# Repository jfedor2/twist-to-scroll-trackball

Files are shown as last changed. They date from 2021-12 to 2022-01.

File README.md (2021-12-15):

# DIY trackball with twist-to-scroll

This repository contains design files and code that can be used to make a fully programmable four-button USB trackball that can scroll by rotating the ball around the vertical axis. It achieves that by having two optical sensors.

Here's a [video](https://www.youtube.com/watch?v=dVZCyMe__IE) demonstrating the twist-to-scroll function.

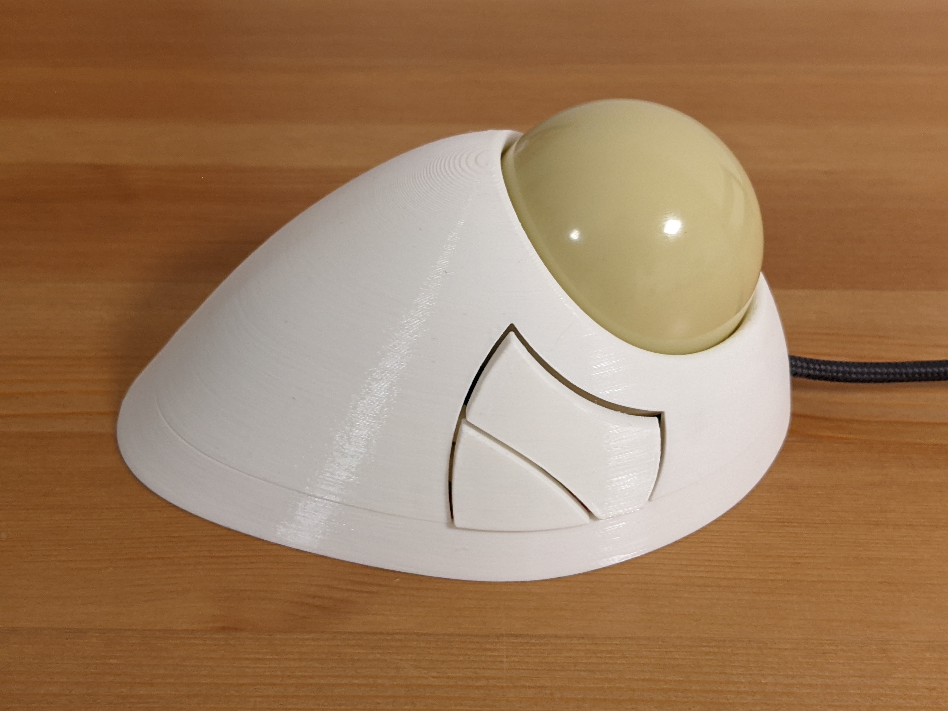
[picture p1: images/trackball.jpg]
Trackball photo


It uses the following components:

* 57.2mm billiard ball
* two PMW3360 optical sensors
* [RP2040+PMW3360 PCB](https://github.com/jfedor2/rp2040-pmw3360)
* [PMW3360 breakout PCB](https://github.com/jfedor2/pmw3360-breakout) for the second sensor
* [button switch mount PCBs](https://github.com/jfedor2/mouse-switch-mount-pcb)
* [3D printed case](3d-models)
* Omron D2FC switches (or similar)
* 2.5mm zirconium oxide (or silicon nitride) bearing balls
* M3x4 screws for mounting the main PCB and assembling the case
* M2x4 screws for mounting the buttons and the secondary PCBs
* USB cable (cut off the device end and solder the wires directly to the PCB)

The main PCB uses the RP2040 chip from Raspberry Pi. The firmware supports remapping of ball and button functions using a configuration tool without the need to recompile the source code. All the configuration is stored on device, so the configuration tool is only needed to change the settings, not during normal use.

The twist-to-scroll function is a work in progress, but it already works pretty well. High resolution scroll is supported (on Windows and in some cases on Linux).

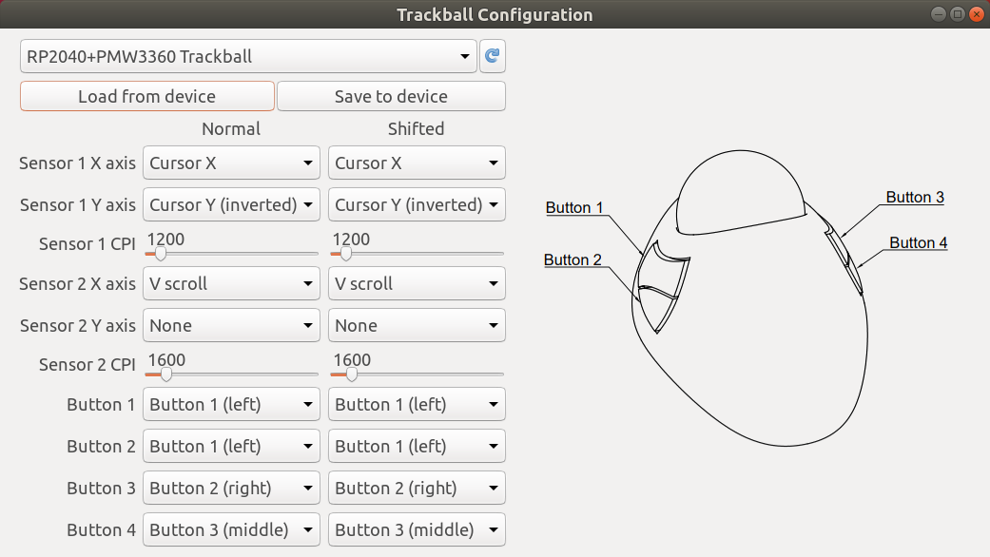
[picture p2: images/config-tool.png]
Configuration tool UI screenshot


So far I only tested the configuration tool on Linux, but it should in theory run on Windows and Mac as well. I will try to provide ready-to-use packages in the future.

The provided [UF2 file](firmware/trackball.uf2) can be used to flash the firmware onto the device. When first connected, a "RPI-RP2" drive will show up and you flash the chip by copying the UF2 file to that drive. If you want to flash it again, hold the BOOT button and press the RESET button on the board.

I printed the case parts with 0.2mm layer height. The top and bottom parts don't need supports, the buttons do.

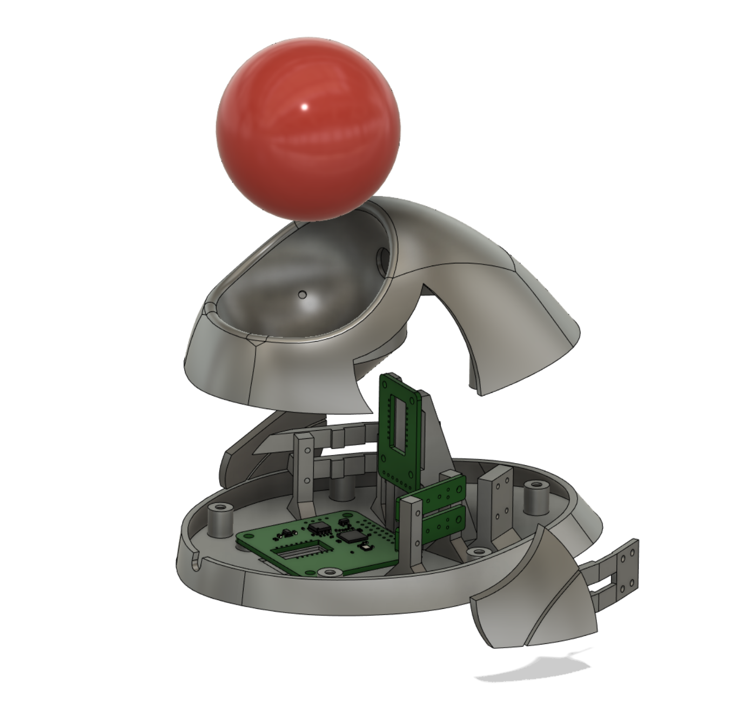
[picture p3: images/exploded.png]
Exploded view


The pin numbers are defined at the top of [trackball.cc](firmware/src/trackball.cc).

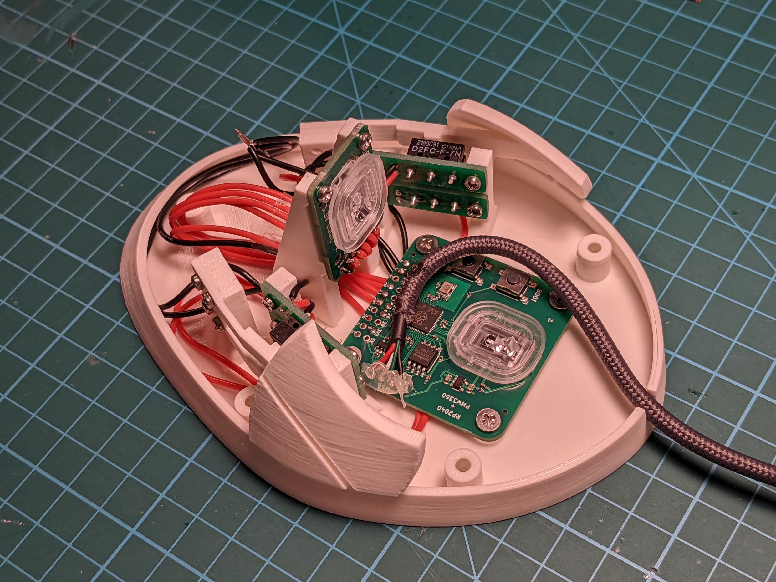
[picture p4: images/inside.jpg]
Insides of the case


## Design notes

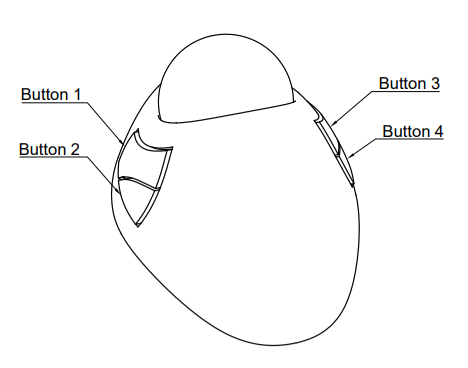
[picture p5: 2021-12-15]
config-tool/trackball.png

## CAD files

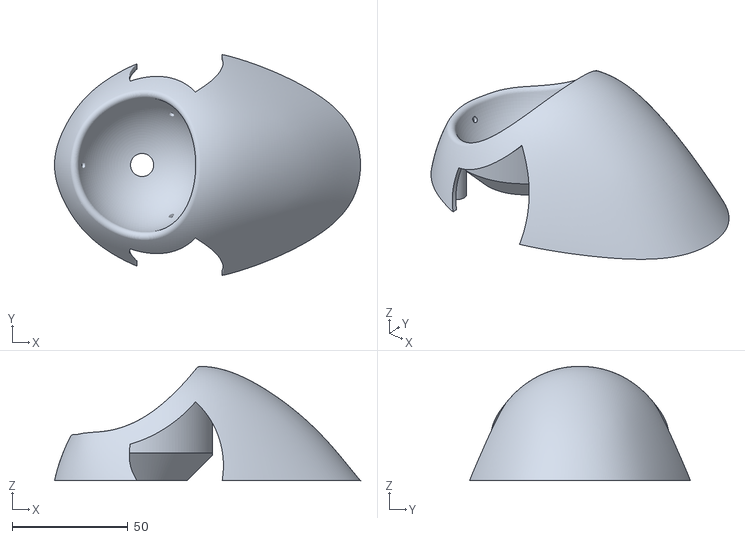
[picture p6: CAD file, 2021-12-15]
3d-models/Trackball13-Top.stl
132.3 x 95.6 x 49.5

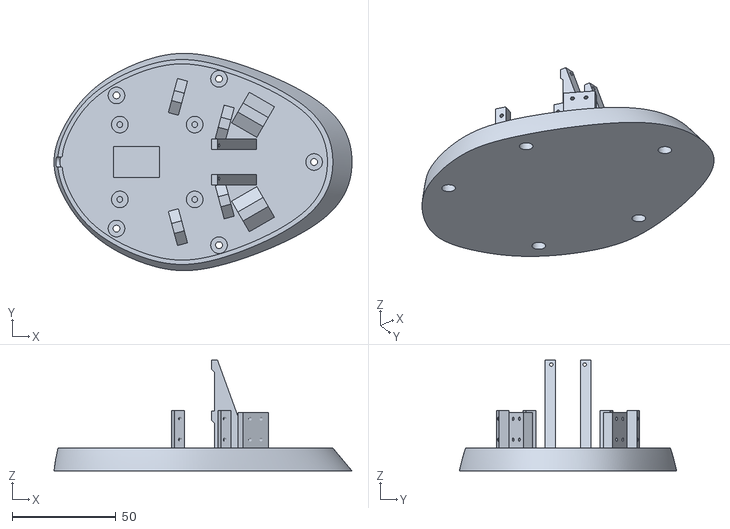
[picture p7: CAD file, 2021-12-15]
3d-models/Trackball13-Bottom.stl
143.3 x 104.5 x 53.2

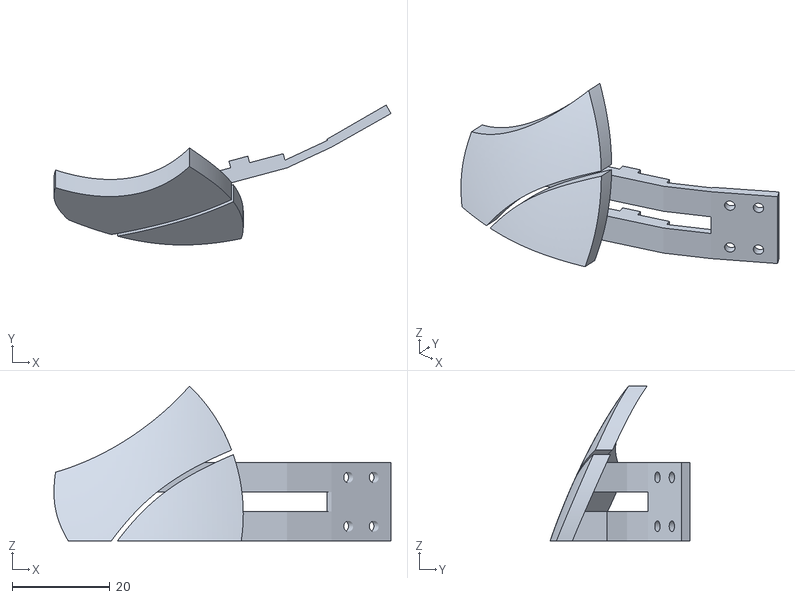
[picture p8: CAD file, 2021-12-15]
3d-models/Trackball13-Buttons-Left.stl
68.9 x 28.6 x 31.7

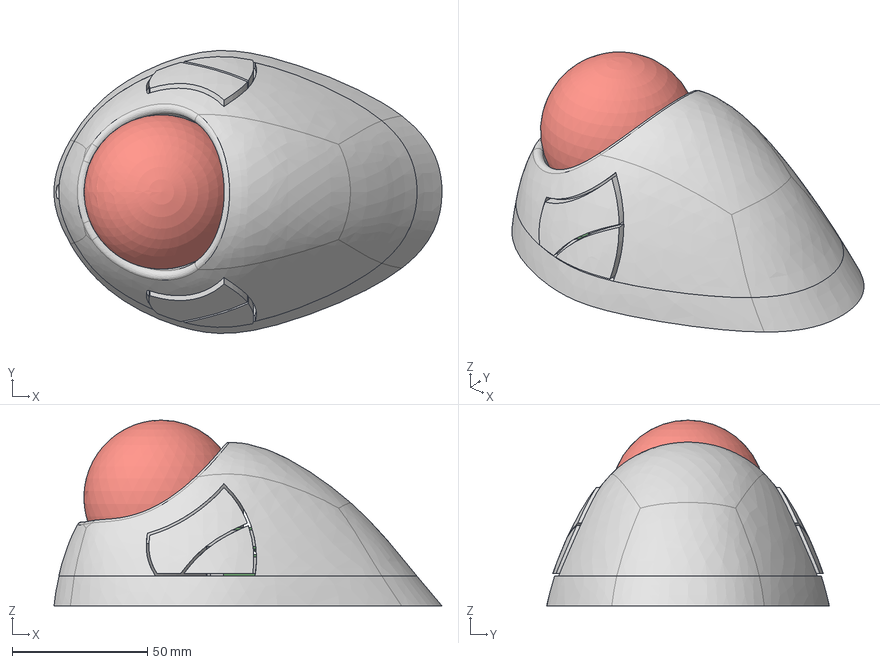
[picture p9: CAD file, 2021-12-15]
3d-models/Trackball13.step
143.3 x 104.4 x 68.6 mm

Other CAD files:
3d-models/Trackball13.f3z

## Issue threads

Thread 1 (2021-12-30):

3D source files

JonnyHaystack, 2021-12-30:
Hi, would you mind uploading the source files for the 3D models? At the moment I'm just trying to put a USB C port cutout in the wall instead of the hole for the cable, but it's a bit tricky to manually patch the cable hole closed. Alternatively, if you could just upload an STL for the bottom part without the cable hole that would make it a lot easier to edit it with a custom port cutout.

I was mostly able to do it with some hacky editing but it comes out a bit weird in the slicer and I'm not sure if it might cause problems when printing :-/
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

jfedor2, 2021-12-31:
I can upload the source file, but for stuff like this you should really start with the STEP file, not the STLs. It won't give you my editing timeline, but removing the cable cutout is as easy as selecting three faces and pressing the del key (at least in Fusion 360).

JonnyHaystack, 2021-12-31:
Thanks. I use OpenSCAD usually so I can't really do anything with the STEP file in that I don't think.

jfedor2, 2021-12-31:
Yeah, the "source" I'm talking about would be a Fusion 360 file, so not useful in OpenSCAD either I'm afraid.

JonnyHaystack, 2021-12-31:
Yeah I know, but in this case I would just remove the cable cutout in Fusion 360 and export it as an STL, then do my thing in OpenSCAD.

Oh, and on an unrelated note, I accidentally printed one of the mouse button things without supports, and it actually printed fine and came out better than the ones that I printed with supports. The first layer had a couple of droopy bits which I clipped off, but other than that it turns out great. My printer isn't anything crazy good either.
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

jfedor2, 2022-01-01:
I added the Fusion 360 file. Good luck!

Closed 2022-01-01.

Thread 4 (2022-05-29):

Why a work in progress?

Steve-Wax, 2022-05-29:
I like your design.  It looks like a cross between the Logitech Trackman Marble Mouse and the Kensington Slim Blade with the best features of each.  I'm thinking of building one.  You mention that the scrolling is a work in progress.  I'm curious why you think that is and what needs to be improved.  Do you think it is good for regular use or should I plan to do some work on it first.  Thanks for the design.

jfedor2, 2022-05-29:
Thank you for the kind words.

I think the scroll works pretty well as it is, but it should ideally be other users to confirm that as I may be a bit biased. I wrote it's a work in progress because it's a bit of a heuristic, the code has to decide whether the user intended to scroll or just make normal cursor tracking motions. So there's some wiggle room for tweaking the constants and it might even be up to personal preference.

But don't let that discourage you from building one, I think it's perfectly usable in its current form. The work-in-progress part just means I make no bold claims about some of the arbitrary decisions necessarily being the optimal ones.

Steve-Wax, 2022-05-30:
Makes sense.  I've ordered the boards and parts.  I'll let you know what I think once they arrive and I have a chance to build it.

Steve-Wax, 2022-07-02:
So I made two of these and have been using them for a few weeks.  Generally I think it is good.  I'm having trouble with the scroll from time to time.  For some time it wasn't recognizing when I wanted to scroll and occasionally it was scrolling when I didn't want it to.  I'm wondering if it is the finish on my ball because the two different mice were acting differently.  I will keep using and experimenting to see if I can figure out what is going on.

The rest is working well.  I did the USB-C mod that  @JonnyHaystack designed.  The only change I would make is putting a ridge on the lower buttons as I can't feel when I'm on the lower button or not.  Thanks for the design.
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

itsnoteasy, 2023-04-30:
I had trouble with the cursor getting intermittent, this worked for me. although lift off detection is important in mouses, it can make trackballs harder to use. you can add these lines to pmw3360.c, near the end, under //set initial cpi resolution

    // LOD: 0x00 disable lift detection, 0x02 = 2mm, 0x03 = 3mm
    write_register(Lift_Config, 0x00);

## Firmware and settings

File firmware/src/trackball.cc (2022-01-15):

/* 
 * The MIT License (MIT)
 *
 * Copyright (c) 2021 Jacek Fedorynski
 * Copyright (c) 2019 Ha Thach (tinyusb.org)
 *
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
 */

#include <math.h>
#include <stdio.h>
#include <stdlib.h>
#include <string.h>

#include <bsp/board.h>
#include <tusb.h>

#include <pico/bootrom.h>
#include <pico/stdlib.h>

#include <hardware/flash.h>
#include <hardware/gpio.h>

#include "crc.h"
#include "pmw3360.h"

// These IDs are bogus. If you want to distribute any hardware using this,
// you will have to get real ones.
#define USB_VID 0xCAFE
#define USB_PID 0xBADA

#define CONFIG_VERSION 1
#define CONFIG_SIZE 26

#define NSENSORS 2
#define NBUTTONS 4

#define PRESUMED_FLASH_SIZE 2097152
#define CONFIG_OFFSET_IN_FLASH (PRESUMED_FLASH_SIZE - FLASH_SECTOR_SIZE)
#define FLASH_CONFIG_IN_MEMORY (((uint8_t*) XIP_BASE) + CONFIG_OFFSET_IN_FLASH)

uint button_pins[NBUTTONS] = { 16, 17, 24, 26 };

#define SENSOR0_SPI spi0
#define SENSOR0_MISO 4
#define SENSOR0_MOSI 3
#define SENSOR0_SCK 2
#define SENSOR0_NCS 9
#define SENSOR1_SPI spi0
#define SENSOR1_MISO 20
#define SENSOR1_MOSI 23
#define SENSOR1_SCK 18
#define SENSOR1_NCS 25

PMW3360 sensors[NSENSORS] = {
    PMW3360(SENSOR0_SPI, SENSOR0_MISO, SENSOR0_MOSI, SENSOR0_SCK, SENSOR0_NCS),
    PMW3360(SENSOR1_SPI, SENSOR1_MISO, SENSOR1_MOSI, SENSOR1_SCK, SENSOR1_NCS),
};

tusb_desc_device_t const desc_device = {
    .bLength = sizeof(tusb_desc_device_t),
    .bDescriptorType = TUSB_DESC_DEVICE,
    .bcdUSB = 0x0200,
    .bDeviceClass = 0x00,
    .bDeviceSubClass = 0x00,
    .bDeviceProtocol = 0x00,
    .bMaxPacketSize0 = CFG_TUD_ENDPOINT0_SIZE,

    .idVendor = USB_VID,
    .idProduct = USB_PID,
    .bcdDevice = 0x0100,

    .iManufacturer = 0x01,
    .iProduct = 0x02,
    .iSerialNumber = 0x00,

    .bNumConfigurations = 0x01,
};

uint8_t const desc_hid_report[] = {
    0x05, 0x01,         // Usage Page (Generic Desktop Ctrls)
    0x09, 0x02,         // Usage (Mouse)
    0xA1, 0x01,         // Collection (Application)
    0x05, 0x01,         //   Usage Page (Generic Desktop Ctrls)
    0x09, 0x02,         //   Usage (Mouse)
    0xA1, 0x02,         //   Collection (Logical)
    0x85, 0x01,         //     Report ID (1)
    0x09, 0x01,         //     Usage (Pointer)
    0xA1, 0x00,         //     Collection (Physical)
    0x05, 0x09,         //       Usage Page (Button)
    0x19, 0x01,         //       Usage Minimum (0x01)
    0x29, 0x08,         //       Usage Maximum (0x08)
    0x95, 0x08,         //       Report Count (8)
    0x75, 0x01,         //       Report Size (1)
    0x25, 0x01,         //       Logical Maximum (1)
    0x81, 0x02,         //       Input (Data,Var,Abs,No Wrap,Linear,Preferred State,No Null Position)
    0x05, 0x01,         //       Usage Page (Generic Desktop Ctrls)
    0x09, 0x30,         //       Usage (X)
    0x09, 0x31,         //       Usage (Y)
    0x95, 0x02,         //       Report Count (2)
    0x75, 0x10,         //       Report Size (16)
    0x16, 0x00, 0x80,   //       Logical Minimum (-32768)
    0x26, 0xFF, 0x7F,   //       Logical Maximum (32767)
    0x81, 0x06,         //       Input (Data,Var,Rel,No Wrap,Linear,Preferred State,No Null Position)
    0xA1, 0x02,         //       Collection (Logical)
    0x85, 0x02,         //         Report ID (2)
    0x09, 0x48,         //         Usage (Resolution Multiplier)
    0x95, 0x01,         //         Report Count (1)
    0x75, 0x02,         //         Report Size (2)
    0x15, 0x00,         //         Logical Minimum (0)
    0x25, 0x01,         //         Logical Maximum (1)
    0x35, 0x01,         //         Physical Minimum (1)
    0x45, 0x78,         //         Physical Maximum (120)
    0xB1, 0x02,         //         Feature (Data,Var,Abs,No Wrap,Linear,Preferred State,No Null Position,Non-volatile)
    0x85, 0x01,         //         Report ID (1)
    0x09, 0x38,         //         Usage (Wheel)
    0x35, 0x00,         //         Physical Minimum (0)
    0x45, 0x00,         //         Physical Maximum (0)
    0x16, 0x00, 0x80,   //         Logical Minimum (-32768)
    0x26, 0xFF, 0x7F,   //         Logical Maximum (32767)
    0x75, 0x10,         //         Report Size (16)
    0x81, 0x06,         //         Input (Data,Var,Rel,No Wrap,Linear,Preferred State,No Null Position)
    0xC0,               //       End Collection
    0xA1, 0x02,         //       Collection (Logical)
    0x85, 0x02,         //         Report ID (2)
    0x09, 0x48,         //         Usage (Resolution Multiplier)
    0x75, 0x02,         //         Report Size (2)
    0x15, 0x00,         //         Logical Minimum (0)
    0x25, 0x01,         //         Logical Maximum (1)
    0x35, 0x01,         //         Physical Minimum (1)
    0x45, 0x78,         //         Physical Maximum (120)
    0xB1, 0x02,         //         Feature (Data,Var,Abs,No Wrap,Linear,Preferred State,No Null Position,Non-volatile)
    0x35, 0x00,         //         Physical Minimum (0)
    0x45, 0x00,         //         Physical Maximum (0)
    0x75, 0x04,         //         Report Size (4)
    0xB1, 0x03,         //         Feature (Const,Var,Abs,No Wrap,Linear,Preferred State,No Null Position,Non-volatile)
    0x85, 0x01,         //         Report ID (1)
    0x05, 0x0C,         //         Usage Page (Consumer)
    0x16, 0x00, 0x80,   //         Logical Minimum (-32768)
    0x26, 0xFF, 0x7F,   //         Logical Maximum (32767)
    0x75, 0x10,         //         Report Size (16)
    0x0A, 0x38, 0x02,   //         Usage (AC Pan)
    0x81, 0x06,         //         Input (Data,Var,Rel,No Wrap,Linear,Preferred State,No Null Position)
    0xC0,               //       End Collection
    0xC0,               //     End Collection
    0xC0,               //   End Collection
    0x06, 0x00, 0xFF,   //   Usage Page (Vendor Defined 0xFF00)
    0x09, 0x20,         //   Usage (0x20)
    0x85, 0x03,         //   Report ID (3)
    0x75, 0x08,         //   Report Size (8)
    0x95, CONFIG_SIZE,  //   Report Count (CONFIG_SIZE)
    0xB1, 0x02,         //   Feature (Data,Var,Abs,No Wrap,Linear,Preferred State,No Null Position,Non-volatile)
    0xC0,               // End Collection
};

#define CONFIG_TOTAL_LEN (TUD_CONFIG_DESC_LEN + TUD_HID_DESC_LEN)
#define EPNUM_HID 0x81

uint8_t const desc_configuration[] = {
    // Config number, interface count, string index, total length, attribute, power in mA
    TUD_CONFIG_DESCRIPTOR(1, 1, 0, CONFIG_TOTAL_LEN, 0, 100),

    // Interface number, string index, protocol, report descriptor len, EP In address, size & polling interval
    TUD_HID_DESCRIPTOR(0, 0, HID_ITF_PROTOCOL_NONE, sizeof(desc_hid_report), EPNUM_HID, CFG_TUD_HID_EP_BUFSIZE, 1)
};

char const* string_desc_arr[] = {
    (const char[]){ 0x09, 0x04 },  // 0: is supported language is English (0x0409)
    "RP2040+PMW3360",              // 1: Manufacturer
    "Trackball",                   // 2: Product
};

struct __attribute__((packed)) hid_report_t {
    uint8_t buttons;
    int16_t dx;
    int16_t dy;
    int16_t vwheel;
    int16_t hwheel;
};

hid_report_t report;

enum class ButtonFunction : int8_t {
    NO_FUNCTION = 0,
    BUTTON1 = 1,
    BUTTON2 = 2,
    BUTTON3 = 3,
    BUTTON4 = 4,
    BUTTON5 = 5,
    BUTTON6 = 6,
    BUTTON7 = 7,
    BUTTON8 = 8,
    CLICK_DRAG = 9,
    SHIFT = 10,
};

enum class SensorFunction : int8_t {
    NO_FUNCTION = 0,
    CURSOR_X = 1,
    CURSOR_Y = 2,
    VERTICAL_SCROLL = 3,
    HORIZONTAL_SCROLL = 4,
    CURSOR_X_INVERTED = -1,
    CURSOR_Y_INVERTED = -2,
    VERTICAL_SCROLL_INVERTED = -3,
    HORIZONTAL_SCROLL_INVERTED = -4,
};

enum class ConfigCommand : int8_t {
    NO_COMMAND = 0,
    RESET_INTO_BOOTSEL = 1,
};

struct __attribute__((packed)) config_t {
    uint8_t version;
    ConfigCommand command;
    SensorFunction sensor_function[NSENSORS][2];
    SensorFunction sensor_shifted_function[NSENSORS][2];
    uint8_t sensor_cpi[NSENSORS];
    uint8_t sensor_shifted_cpi[NSENSORS];
    ButtonFunction button_function[NBUTTONS];
    ButtonFunction button_shifted_function[NBUTTONS];
    uint32_t crc32;
};

config_t config = {
    .version = CONFIG_VERSION,
    .command = ConfigCommand::NO_COMMAND,
    .sensor_function = {
        { SensorFunction::CURSOR_X, SensorFunction::CURSOR_Y_INVERTED },
        { SensorFunction::VERTICAL_SCROLL, SensorFunction::NO_FUNCTION },
    },
    .sensor_shifted_function = {
        { SensorFunction::CURSOR_X, SensorFunction::CURSOR_Y_INVERTED },
        { SensorFunction::VERTICAL_SCROLL, SensorFunction::NO_FUNCTION },
    },
    .sensor_cpi = {
        600 / 100,
        800 / 100,
    },
    .sensor_shifted_cpi = {
        600 / 100,
        800 / 100,
    },
    .button_function = {
        ButtonFunction::BUTTON1,
        ButtonFunction::BUTTON1,
        ButtonFunction::BUTTON2,
        ButtonFunction::BUTTON3,
    },
    .button_shifted_function = {
        ButtonFunction::BUTTON1,
        ButtonFunction::BUTTON1,
        ButtonFunction::BUTTON2,
        ButtonFunction::BUTTON3,
    },
    .crc32 = 0,
};

uint8_t resolution_multiplier = 0;

int accumulated_scroll[NSENSORS][2] = { 0 };
uint64_t last_scroll_timestamp[NSENSORS][2] = { 0 };
uint32_t prev_pin_state = 0xffffffff;
bool click_drag = false;
uint8_t current_cpi[NSENSORS] = { 0 };
bool scroll_mode = false;
bool not_scroll_mode = false;
float running_avg_x = 0;
float running_avg_y = 0;
float running_avg_hscroll = 0;
float running_avg_vscroll = 0;

int16_t handle_scroll(int sensor, int axis, int16_t movement, uint8_t multiplier_mask, float* running_avg_scroll) {
    int16_t ret = 0;
    *running_avg_scroll += 0.1 * movement / current_cpi[sensor];
    if (resolution_multiplier & multiplier_mask) {
        ret = movement;
    } else {
        if (movement != 0) {
            last_scroll_timestamp[sensor][axis] = time_us_64();
            accumulated_scroll[sensor][axis] += movement;
            int ticks = accumulated_scroll[sensor][axis] / 120;
            accumulated_scroll[sensor][axis] -= ticks * 120;
            ret = ticks;
        } else {
            if ((accumulated_scroll[sensor][axis] != 0) &&
                (time_us_64() - last_scroll_timestamp[sensor][axis] > 1000000)) {
                accumulated_scroll[sensor][axis] = 0;
            }
        }
    }
    return ret;
}

/*
 * This function tries to decide whether we're scrolling or moving the cursor.
 * It then commits to one or the other until the ball stops moving.
 * If it decides that we're moving the cursor then it zeroes any scroll input.
 * It doesn't currently cancel cursor movement when it decides that we're
 * scrolling.
 * The sensor axes functions are configurable, but below logic probably only
 * makes sense if the default mapping is used. It might also slightly interfere
 * with a configuration where you have the ball set to scroll when "shift"
 * button is held, so keep that in mind.
 * False positives still happen occasionally, you can try to tweak the
 * thresholds to improve the situation.
 * In theory it is CPI agnostic, but I haven't done a lot of testing with
 * different CPI values.
 * Oh, and the running averages are sensitive to how many samples per second
 * we're getting from the sensors, at the time it was being written it was
 * around 500.
 */
void handle_twist_to_scroll() {
    if (fabs(running_avg_x) < 0.1 / 12 && fabs(running_avg_y) < 0.1 / 12) {
        not_scroll_mode = false;
    }

    if (fabs(running_avg_vscroll) < 0.1 / 16) {
        scroll_mode = false;
    }

    if (!scroll_mode && (running_avg_x * running_avg_x + running_avg_y * running_avg_y > 4.0 / (12 * 12))) {
        not_scroll_mode = true;
    }

    if (!not_scroll_mode && running_avg_vscroll * running_avg_vscroll > 4.0 / (16 * 16)) {
        scroll_mode = true;
    }

    if (!scroll_mode || not_scroll_mode) {
        report.vwheel = 0;
        for (int sensor = 0; sensor < NSENSORS; sensor++) {
            for (int axis = 0; axis < 2; axis++) {
                // ignoring the shifted function for now...
                if (config.sensor_function[sensor][axis] == SensorFunction::VERTICAL_SCROLL ||
                    config.sensor_function[sensor][axis] == SensorFunction::VERTICAL_SCROLL_INVERTED) {
                    accumulated_scroll[sensor][axis] = 0;
                }
            }
        }
    }
}

void hid_task() {
    if (!tud_hid_ready()) {
        return;
    }

    memset(&report, 0, sizeof(report));

    uint32_t pin_state = gpio_get_all();

    bool shifted = false;

    // first pass to determine if we're in shifted state
    for (int i = 0; i < NBUTTONS; i++) {
        if (config.button_function[i] == ButtonFunction::SHIFT &&
            !(pin_state & (1 << button_pins[i]))) {
            shifted = true;
        }
    }

    // set CPI if not already correct
    for (int i = 0; i < NSENSORS; i++) {
        uint8_t wanted_cpi = shifted ? config.sensor_shifted_cpi[i] : config.sensor_cpi[i];
        if (current_cpi[i] != wanted_cpi && wanted_cpi >= 1 && wanted_cpi <= 120) {
            sensors[i].set_cpi(wanted_cpi * 100);
            current_cpi[i] = wanted_cpi;
        }
    }

    for (int i = 0; i < NBUTTONS; i++) {
        ButtonFunction button_function =
            shifted ? config.button_shifted_function[i] : config.button_function[i];
        if (config.button_function[i] == ButtonFunction::SHIFT) {
            button_function = ButtonFunction::NO_FUNCTION;
        }
        switch (button_function) {
            case ButtonFunction::NO_FUNCTION:
            case ButtonFunction::SHIFT:
                break;
            case ButtonFunction::BUTTON1:
            case ButtonFunction::BUTTON2:
            case ButtonFunction::BUTTON3:
            case ButtonFunction::BUTTON4:
            case ButtonFunction::BUTTON5:
            case ButtonFunction::BUTTON6:
            case ButtonFunction::BUTTON7:
            case ButtonFunction::BUTTON8: {
                int button = static_cast<int>(button_function) - 1;
                if (!(pin_state & (1 << button_pins[i]))) {
                    report.buttons |= 1 << button;
                }
                break;
            }
            case ButtonFunction::CLICK_DRAG:
                if ((prev_pin_state & (1 << button_pins[i])) &&
                    !(pin_state & (1 << button_pins[i]))) {
                    click_drag = !click_drag;
                }
                break;
        }
    }

    if (click_drag) {
        report.buttons |= 1 << 0;
    }

    prev_pin_state = pin_state;

    running_avg_x *= 0.9;
    running_avg_y *= 0.9;
    running_avg_vscroll *= 0.9;
    running_avg_hscroll *= 0.9;

    for (int sensor = 0; sensor < NSENSORS; sensor++) {
        sensors[sensor].update();
        for (int axis = 0; axis < 2; axis++) {
            int16_t movement = sensors[sensor].movement[axis];
            SensorFunction sensor_function =
                shifted ? config.sensor_shifted_function[sensor][axis] : config.sensor_function[sensor][axis];
            if (static_cast<int>(sensor_function) < 0) {
                movement *= -1;
            }
            switch (sensor_function) {
                case SensorFunction::NO_FUNCTION:
                    break;
                case SensorFunction::CURSOR_X:
                case SensorFunction::CURSOR_X_INVERTED:
                    report.dx += movement;
                    running_avg_x += 0.1 * movement / current_cpi[sensor];
                    break;
                case SensorFunction::CURSOR_Y:
                case SensorFunction::CURSOR_Y_INVERTED:
                    report.dy += movement;
                    running_avg_y += 0.1 * movement / current_cpi[sensor];
                    break;
                case SensorFunction::VERTICAL_SCROLL:
                case SensorFunction::VERTICAL_SCROLL_INVERTED:
                    report.vwheel += handle_scroll(sensor, axis, movement, 1 << 0, &running_avg_vscroll);
                    break;
                case SensorFunction::HORIZONTAL_SCROLL:
                case SensorFunction::HORIZONTAL_SCROLL_INVERTED:
                    report.hwheel += handle_scroll(sensor, axis, movement, 1 << 2, &running_avg_hscroll);
                    break;
            }
        }
    }

    // uncomment to have pressing all buttons reset into BOOTSEL
    // (convenient during development)
    // if (!(pin_state & (1 << button_pins[0]) ||
    //       pin_state & (1 << button_pins[1]) ||
    //       pin_state & (1 << button_pins[2]) ||
    //       pin_state & (1 << button_pins[3]))) {
    //     reset_usb_boot(0, 0);
    // }

    handle_twist_to_scroll();

    tud_hid_report(1, &report, sizeof(report));
}

void pin_init(uint pin) {
    gpio_init(pin);
    gpio_set_dir(pin, GPIO_IN);
    gpio_pull_up(pin);
}

void pins_init() {
    for (int i = 0; i < NBUTTONS; i++) {
        pin_init(button_pins[i]);
    }
}

void sensors_init() {
    for (int i = 0; i < NSENSORS; i++) {
        sensors[i].init();
    }
}

void run_config_command() {
    // we probably shouldn't do this for config read from flash
    // or let's just not write any non-null command to flash
    if (config.command == ConfigCommand::RESET_INTO_BOOTSEL) {
        reset_usb_boot(0, 0);
    }
}

bool checksum_ok(const uint8_t* buffer) {
    return crc32(buffer, CONFIG_SIZE - 4) == ((config_t*) buffer)->crc32;
}

bool version_ok(const uint8_t* buffer) {
    return ((config_t*) buffer)->version == CONFIG_VERSION;
}

void load_config() {
    if (checksum_ok(FLASH_CONFIG_IN_MEMORY) && version_ok(FLASH_CONFIG_IN_MEMORY)) {
        memcpy(&config, FLASH_CONFIG_IN_MEMORY, CONFIG_SIZE);
    }
}

void persist_config() {
    uint8_t buffer[FLASH_PAGE_SIZE];
    memset(buffer, 0, sizeof(buffer));
    memcpy(buffer, &config, CONFIG_SIZE);
    uint32_t ints = save_and_disable_interrupts();
    flash_range_erase(CONFIG_OFFSET_IN_FLASH, FLASH_SECTOR_SIZE);
    flash_range_program(CONFIG_OFFSET_IN_FLASH, buffer, FLASH_PAGE_SIZE);
    restore_interrupts(ints);
}

int main() {
    stdio_init_all();
    board_init();
    load_config();
    pins_init();
    sensors_init();
    tusb_init();

    while (true) {
        tud_task();  // tinyusb device task
        hid_task();
    }

    return 0;
}

// Invoked when device is mounted
void tud_mount_cb() {
    // reset hi-res scroll for when we reboot from Windows into Linux
    resolution_multiplier = 0;
}

// Invoked when received GET DEVICE DESCRIPTOR
// Application return pointer to descriptor
uint8_t const* tud_descriptor_device_cb() {
    return (uint8_t const*) &desc_device;
}

// Invoked when received GET HID REPORT DESCRIPTOR
// Application return pointer to descriptor
// Descriptor contents must exist long enough for transfer to complete
uint8_t const* tud_hid_descriptor_report_cb(uint8_t itf) {
    return desc_hid_report;
}

// Invoked when received GET_REPORT control request
// Application must fill buffer report's content and return its length.
// Return zero will cause the stack to STALL request
uint16_t tud_hid_get_report_cb(uint8_t itf, uint8_t report_id, hid_report_type_t report_type, uint8_t* buffer, uint16_t reqlen) {
    if (report_id == 2 && reqlen >= 1) {
        memcpy(buffer, &resolution_multiplier, 1);
        return 1;
    }
    if (report_id == 3 && reqlen >= CONFIG_SIZE) {
        config.crc32 = crc32((uint8_t*) &config, CONFIG_SIZE - 4);
        memcpy(buffer, &config, CONFIG_SIZE);
        return CONFIG_SIZE;
    }

    return 0;
}

// Invoked when received SET_REPORT control request or
// received data on OUT endpoint ( Report ID = 0, Type = 0 )
void tud_hid_set_report_cb(uint8_t itf, uint8_t report_id, hid_report_type_t report_type, uint8_t const* buffer, uint16_t bufsize) {
    if (report_id == 2 && bufsize >= 1) {
        memcpy(&resolution_multiplier, buffer, 1);
    }
    if (report_id == 3 && bufsize >= CONFIG_SIZE) {
        if (checksum_ok(buffer) && version_ok(buffer)) {
            memcpy(&config, buffer, CONFIG_SIZE);
            run_config_command();
            persist_config();
        }
    }
}

// Invoked when received GET CONFIGURATION DESCRIPTOR
// Application return pointer to descriptor
// Descriptor contents must exist long enough for transfer to complete
uint8_t const* tud_descriptor_configuration_cb(uint8_t index) {
    return desc_configuration;
}

static uint16_t _desc_str[32];

// Invoked when received GET STRING DESCRIPTOR request
// Application return pointer to descriptor, whose contents must exist long enough for transfer to complete
uint16_t const* tud_descriptor_string_cb(uint8_t index, uint16_t langid) {
    uint8_t chr_count;

    if (index == 0) {
        memcpy(&_desc_str[1], string_desc_arr[0], 2);
        chr_count = 1;
    } else {
        // Note: the 0xEE index string is a Microsoft OS 1.0 Descriptors.
        // https://docs.microsoft.com/en-us/windows-hardware/drivers/usbcon/microsoft-defined-usb-descriptors

        if (!(index < sizeof(string_desc_arr) / sizeof(string_desc_arr[0])))
            return NULL;

        const char* str = string_desc_arr[index];

        // Cap at max char
        chr_count = strlen(str);
        if (chr_count > 31)
            chr_count = 31;

        // Convert ASCII string into UTF-16
        for (uint8_t i = 0; i < chr_count; i++) {
            _desc_str[1 + i] = str[i];
        }
    }

    // first byte is length (including header), second byte is string type
    _desc_str[0] = (TUSB_DESC_STRING << 8) | (2 * chr_count + 2);

    return _desc_str;
}

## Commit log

2022-01-01 Add Fusion 360 file
    [Trackball13.f3z]
2022-01-15 Don't fetch sensor data if !tud_hid_ready()
    Moves the tud_hid_ready() check to the beginning of the hid_task()
    function, so that we don't drop sensor readings if USB is not ready.
    With this change, the sensor keeps accumulating the deltas until we're
    ready for them.
    Also changes the default CPI to half of the previous values, which
    should hopefully match previous behavior now that we're not dropping
    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
